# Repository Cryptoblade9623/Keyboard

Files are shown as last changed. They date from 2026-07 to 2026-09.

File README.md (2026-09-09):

# Keyboard
A custom keyboard with a white sakura theme and a rotary encoder.
I'm making this keyboard to have an upgrade from my dying membrane keyboard that also have a lot of the keycaps missing.
I also hope that this will give me some more experience in designing PCBs and 3D models.
Because it is quite a large keyboard that I will be 3D - printing in different parts, I found some metal rods to hold them together and provide some structural support.





Instructions

1.Solder all the diodes on to the PCB

2.Place all the Mill-Max hotswap sockets into their holes

3.Stick heat resistant tape over them in top rows to keep them in place while soldering

4.Solder all the hotswap sockets

5.Solder the pin headers

6.Solder the ESP32 onto the pin headers

7.Solder the Ec11x rotary encoder on to the PCB

8.Flash the ESP32 with the firmware

9.Screw in the PCB-mount stabilizers

10.Solder 4 wires onto the 4 pads of the USBC breakout board

11.Solder 2 small capacitors and 1 big capacitor in parallel on the 5V and GND wires

12.Place heat shrink tubing to cover the solder joints on the wires 

13.Superglue the USBC board into its slot inside the Left-Base part

14.Cut the all the metal rods to 50mm

15.Join the Base pieces together with the metal rods in their slots

16.Join all the Border pieces together again using the metal rods

17.Superglue all the mountain, sakura, grass and tree pieces onto the Scenery Border piece

18.Superglue both halves of the plate together

19.Press the heat set inserts into the Border piece with a soldering iron.

20.Slot the loose wires of the USBC board though the vertical slot hole in the PCB

21.Solder the USBC wires to the D+, D-, GND and RAW of the MCU

22.Stack the parts in the order: base, PCB, plate, border and screw them all together using the M3 bolts

23.Push in the switches

24.Push in all the keycaps onto their assigned switches

25.Snap both pieces of the knob together and push the combined knob onto the rotary encoder stem

And you're done!

| Name | Purpose | Price (USD) | Seller | Link |

| :--- | :--- | :--- | :--- |

| Screws & Standoffs | Spacing, mounting, and securing internal circuit boards | $2.23 | AliExpress |[Link](https://www.aliexpress.com/item/1005008314123679.html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)|

| 100nF Capacitors | Providing smooth current flow to the MCU | $2.27 | AliExpress |[Link](https://www.aliexpress.com/item/1005008314123679.html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)|

| PCB Stabilizers | Stabilizing large mechanical keyboard keys (e.g., Spacebar, Shift) | $10.58 | AliExpress |[Link](https://www.aliexpress.com/item/4001143514438.html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)|

| Keycaps | Providing durable, custom keycaps for mechanical keyboards | $7.74 | AliExpress |[Link](https://www.aliexpress.com/item/4001143514438.html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)|

| Mechanical Switches | Actuating keystrokes quietly and smoothly in hot-swap keyboards | $19.67 | AliExpress |[Link](https://www.aliexpress.com/item/1005012344423067.html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)|

| Rotary Encoder | Providing rotary control and navigation inputs | $2.75 | AliExpress |[Link](https://www.aliexpress.com/item/1005012344423067.html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)|

| Development Board | Processing core logic, Wi-Fi, and Bluetooth functions | $7.10 | AliExpress |[Link](https://www.aliexpress.com/item/1005007319706057.html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)|

| Hot-swap PCB Sockets | Enabling easy and simple mechanical switch replacement on a custom PCB | $14.77 | AliExpress |[Link](https://www.aliexpress.com/item/1005007319706057.html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)|

| USB Type-C Connector | Providing power delivery and data transfer interfaces | $1.25 | AliExpress |[Link](https://www.aliexpress.com/item/1005007319706057.html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)|

| Steel Rod Axles | Acting as structural pins or shafts for moving components | $4.58 | AliExpress |[Link](https://www.aliexpress.com/item/1005007319706057.html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)|

| Heatshrink | Cover soldered wire joints to prevent shorting | $0.85 | AliExpress |[Link](https://www.aliexpress.com/item/1005008538975205.html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)|

| 10uF Capacitors | Providing smooth current flow to the MCU | $1.42 | AliExpress |[Link](https://www.aliexpress.com/item/1005008538975205.html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)|

| Threaded Heat Set Inserts | Providing a thread to screw into | $2.30 | AliExpress |[Link](https://www.aliexpress.com/item/1005008666672949.html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)|

| Copper Braid | Remove excess solder | $3.16 | AliExpress |[Link](https://www.aliexpress.com/item/1005008666672949.html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|)

| Custom PCB | Connecting all the mechanical switches and rotary encoder to the MCU | $28.80 | JLCPCB |-|

| 3D Printed Case | Physical housing or structural frame for the custom keyboard | $3.00 | Printing Legion |-|

| Shipping and Taxes - $16.47

| Grand Total - $128.94|

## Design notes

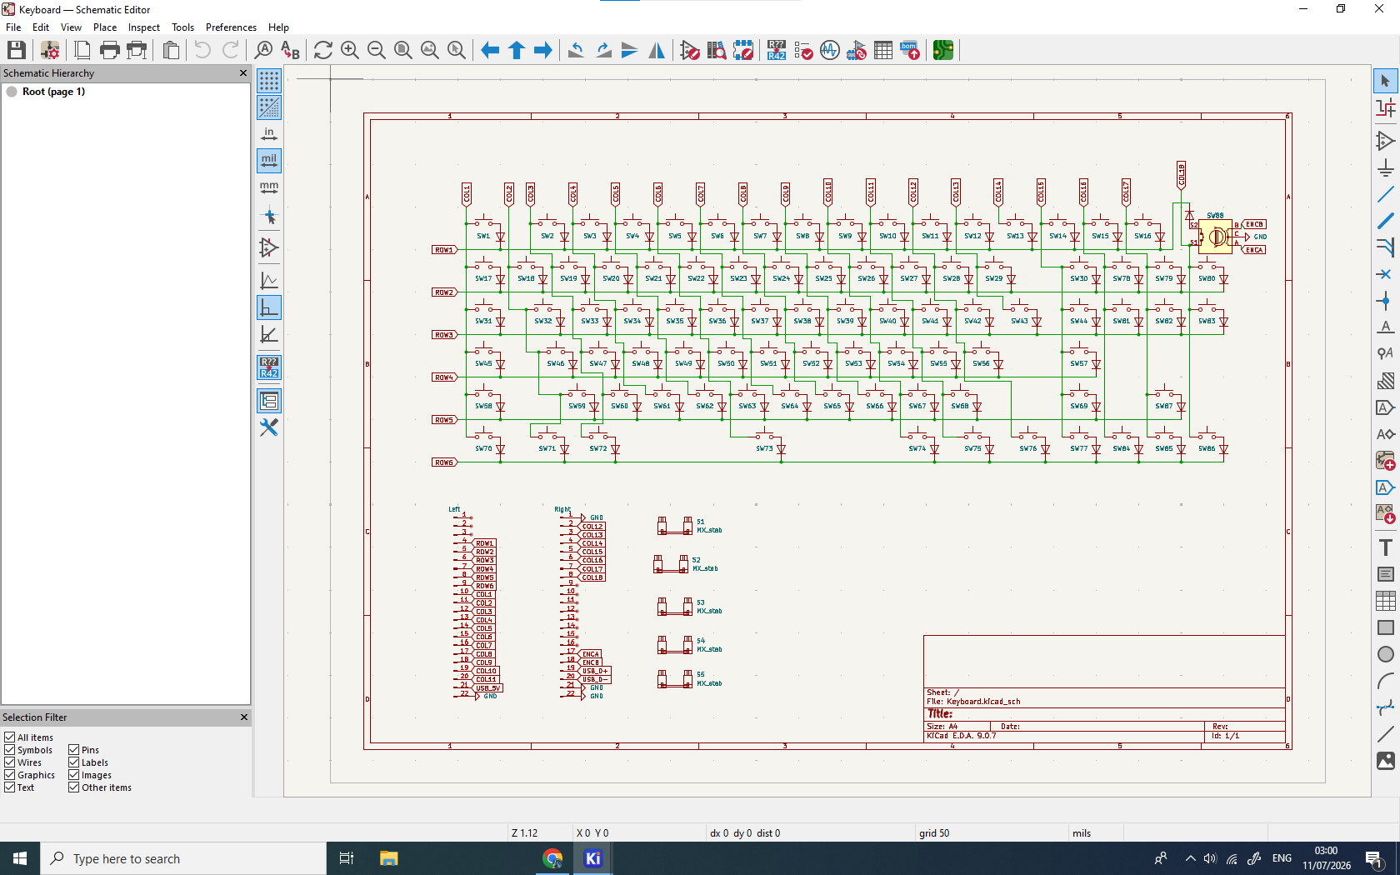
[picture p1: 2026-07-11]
Pictures/Schematic.png

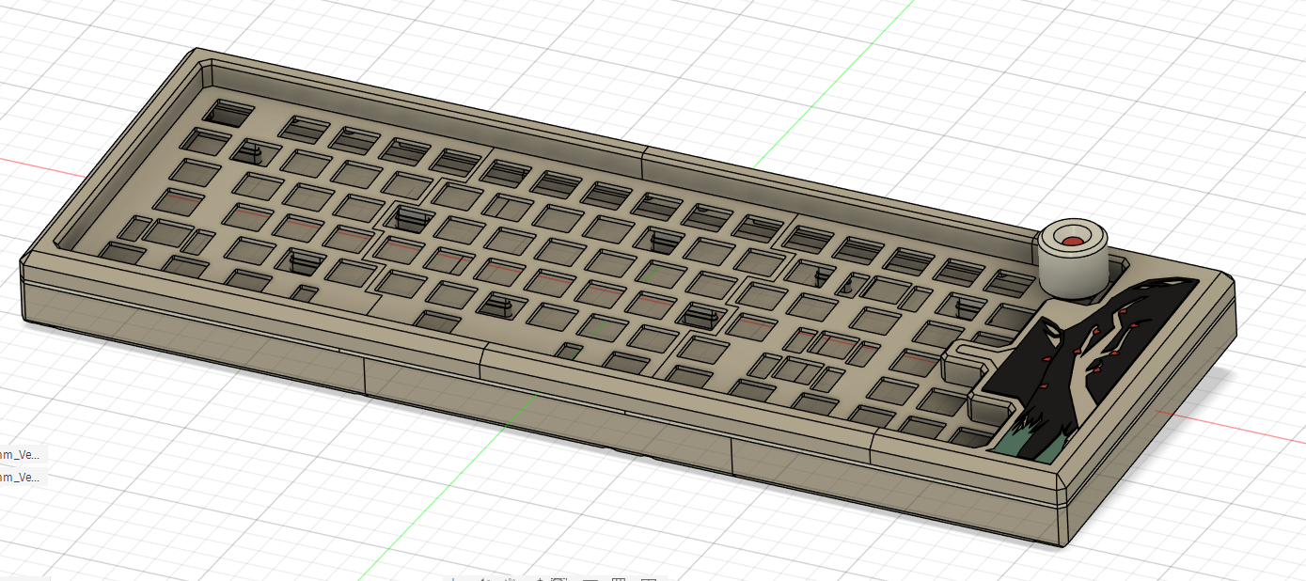
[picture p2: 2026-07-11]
Pictures/Screenshot 2026-06-25 210934.png

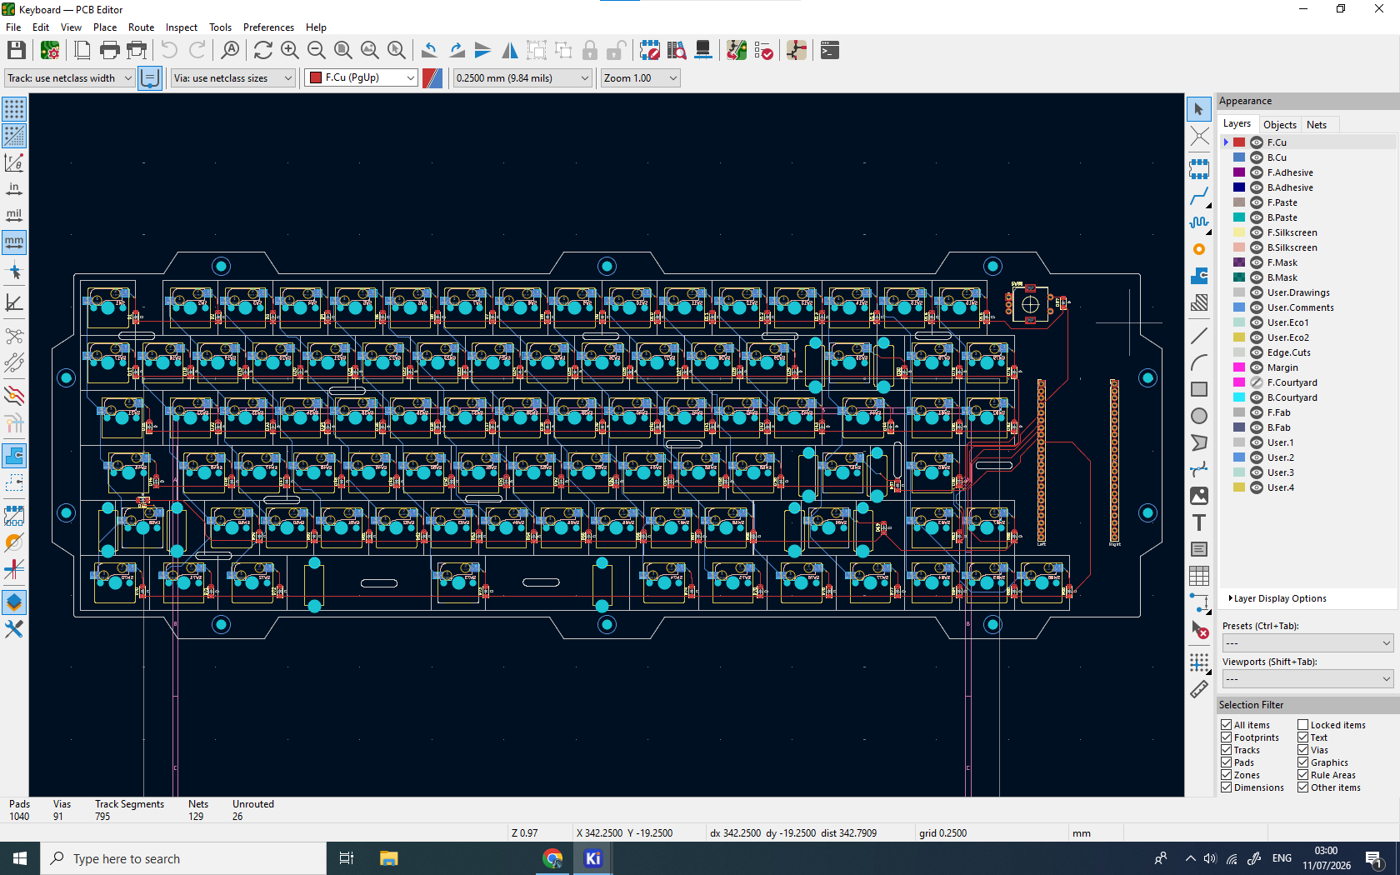
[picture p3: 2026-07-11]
Pictures/PCB.png

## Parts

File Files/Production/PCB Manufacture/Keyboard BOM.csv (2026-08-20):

Name | Purpose | Price | Seller | Link
Screws | Mounting and securing 3D printed parts | $2.23 | AliExpress | https://www.aliexpress.com/item/1005008314123679.html?mp=1
Stabilizers | Preventing keycap rattle for larger keys | $10.58 | AliExpress | https://www.aliexpress.com/item/4001143514438.html?mp=1
Keycaps | Providing a solid surface to type on | $7.74 | AliExpress | https://www.aliexpress.com/item/1005009314900504.html?mp=1
Mechanical Swiches | Registering keystrokes and completing a circuit to alert the MCU | $19.67 | AliExpress | https://www.aliexpress.com/item/1005012344423067.html?mp=1
Rotary Encoder | Providing volume control | $2.75 | AliExpress | https://www.aliexpress.com/item/1005005983134515.html?mp=1
Development Board | Controlling the enitre board and sending signals to the computer | $7.10 | AliExpress | https://www.aliexpress.com/item/1005007319706057.html?mp=1
Hotswap Sockets | Enabling future customizability | $14.77 | AliExpress | https://www.aliexpress.com/item/1005008467527706.html?mp=1
USBC breakout board | Provding power from the computer and data to the computer | $1.25 | AliExpress | https://www.aliexpress.com/item/1005004796961137.html?mp=1
Steel rods | Providing structural support | $4.58 | AliExpress | https://www.aliexpress.com/item/1005009384686024.html?mp=1
Copper Braid | Remove excess solder | $3.16 | AliExpress | https://www.aliexpress.com/item/1005006361511422.html?mp=1
Heatshrink | Cover soldered wire joints | $0.85 | AliExpress | https://www.aliexpress.com/item/1005008538975205.html?mp=1
10uF Capcitor | Smooth power intake to the MCU | $1.42 | AliExpress | https://www.aliexpress.com/item/1005011924154857.html?mp=1
0.1uF Capacitor | Smooth power intake to the MCU | $2.27 | AliExpress | https://www.aliexpress.com/item/1005004982415166.html?scm_id=1007.40050.354490.0&scm-url=1007.40050.354490.0
Threaded Inserts | Providing a thread to screw into | $2.30 | AliExpress | https://www.aliexpress.com/item/1005008666672949.html?curPageLogUid=Rat0uCX0YUx0
PCB | Connecting all the swiches to the MCU | $28.80 | JLCPCB | https://cart.jlcpcb.com/shopcart/cartEdit/?id=c33698ba8980452dbe9859648d54b1e7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
3D Printed Parts | Physical housing | $3.00 | Printing Legion | -
Shipping % Taxes |  | $16.47
Total |  | $128.94

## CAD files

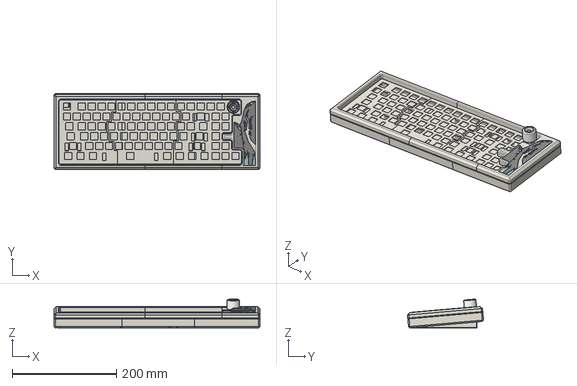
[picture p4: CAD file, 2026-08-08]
Files/Production/3D Files/.step/Keyboard19.step
395.7 x 146.2 x 55.5 mm
D_SOD-123 x 88
旋转编码器

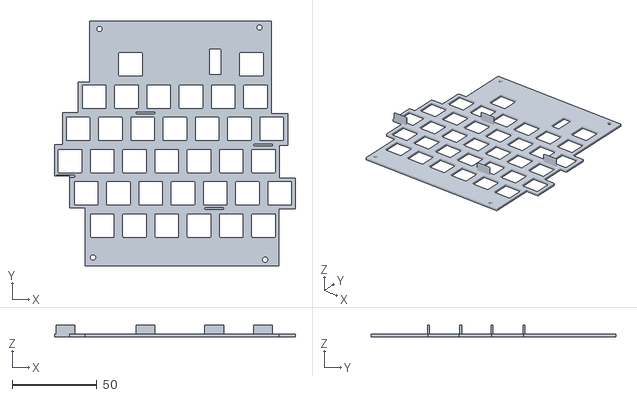
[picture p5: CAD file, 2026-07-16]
Files/Production/3D Files/.stl/Middle Plate.stl.stl
142.4 x 144.8 x 6.96

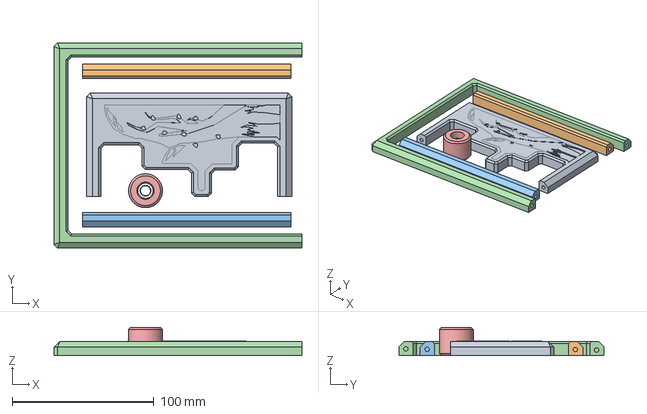
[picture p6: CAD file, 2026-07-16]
Files/Production/3D Files/.step/Borders + Knob Top.step
175.0 x 144.8 x 20.0 mm
D_SOD-123 x 88

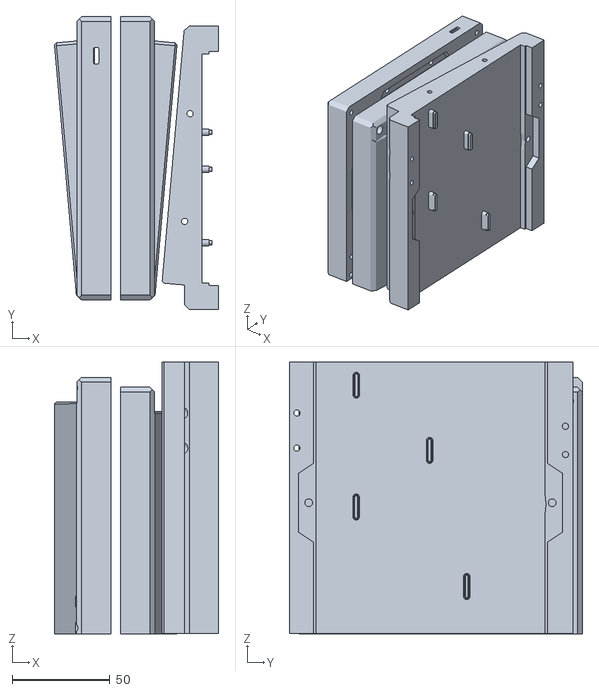
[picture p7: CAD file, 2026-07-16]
Files/Production/3D Files/.stl/Base.stl
83.8 x 149.6 x 138.6

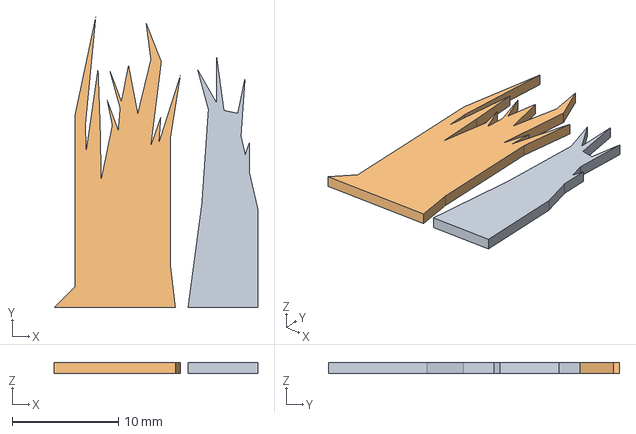
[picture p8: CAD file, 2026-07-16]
Files/Production/3D Files/.step/Grass.step
19.2 x 27.4 x 1.05 mm
D_SOD-123 x 88

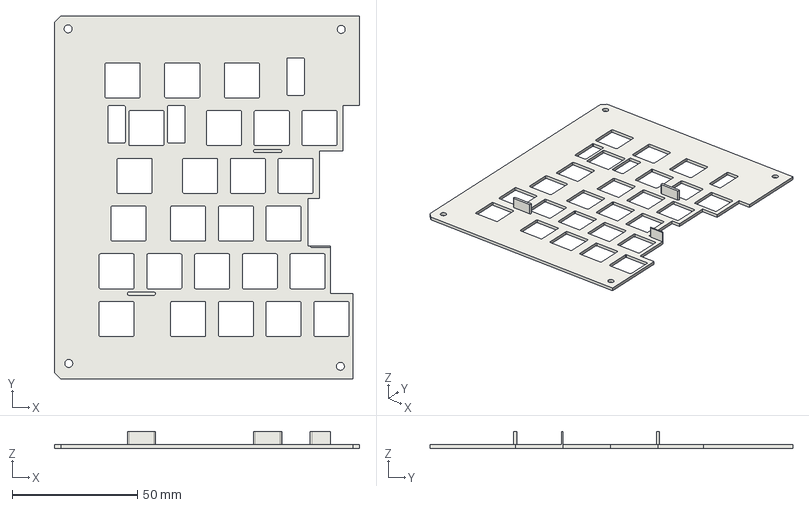
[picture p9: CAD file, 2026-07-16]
Files/Production/3D Files/.step/Left Plate.step
121.7 x 144.8 x 6.96 mm
D_SOD-123 x 88

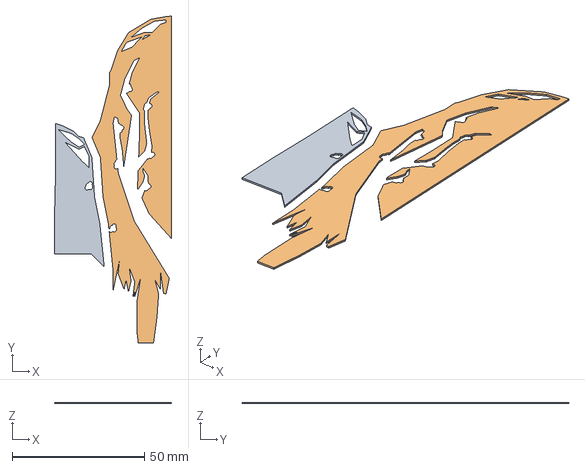
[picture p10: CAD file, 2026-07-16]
Files/Production/3D Files/.step/Mountains.step
44.3 x 123.6 x 0.55 mm
D_SOD-123 x 88

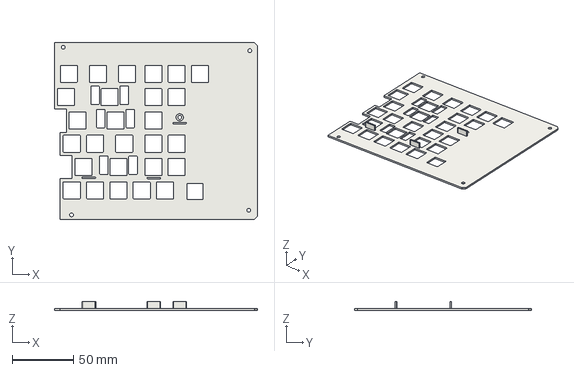
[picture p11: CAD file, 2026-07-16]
Files/Production/3D Files/.step/Right Plate.step
166.0 x 144.8 x 6.96 mm
D_SOD-123 x 88

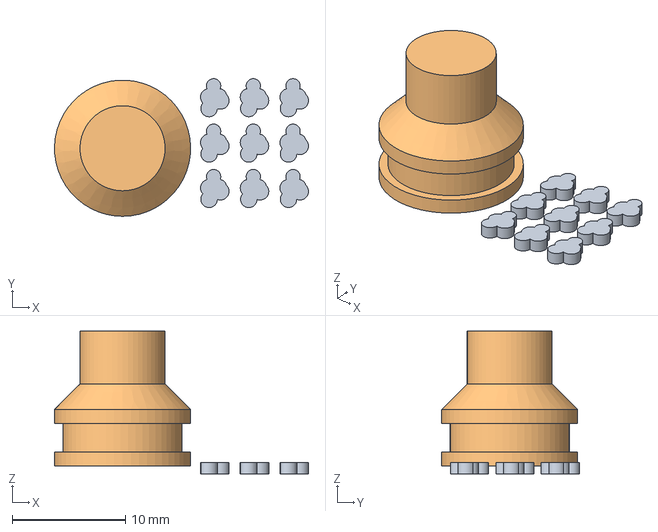
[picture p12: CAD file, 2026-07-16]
Files/Production/3D Files/.step/Sakura + Knob Inside.step
22.4 x 12.1 x 12.6 mm
D_SOD-123 x 88

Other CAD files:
Files/Production/3D Files/.step/Middle Plate.step
Files/Production/3D Files/.stl/Borders + Knob Top.stl
Files/Production/3D Files/.stl/Grass.stl
Files/Production/3D Files/.stl/Keyboard19.stl
Files/Production/3D Files/.stl/Left Plate.stl
Files/Production/3D Files/.stl/Mountains.stl
Files/Production/3D Files/.stl/Right Plate.stl
Files/Production/3D Files/.stl/Sakura + Knob Inside.stl

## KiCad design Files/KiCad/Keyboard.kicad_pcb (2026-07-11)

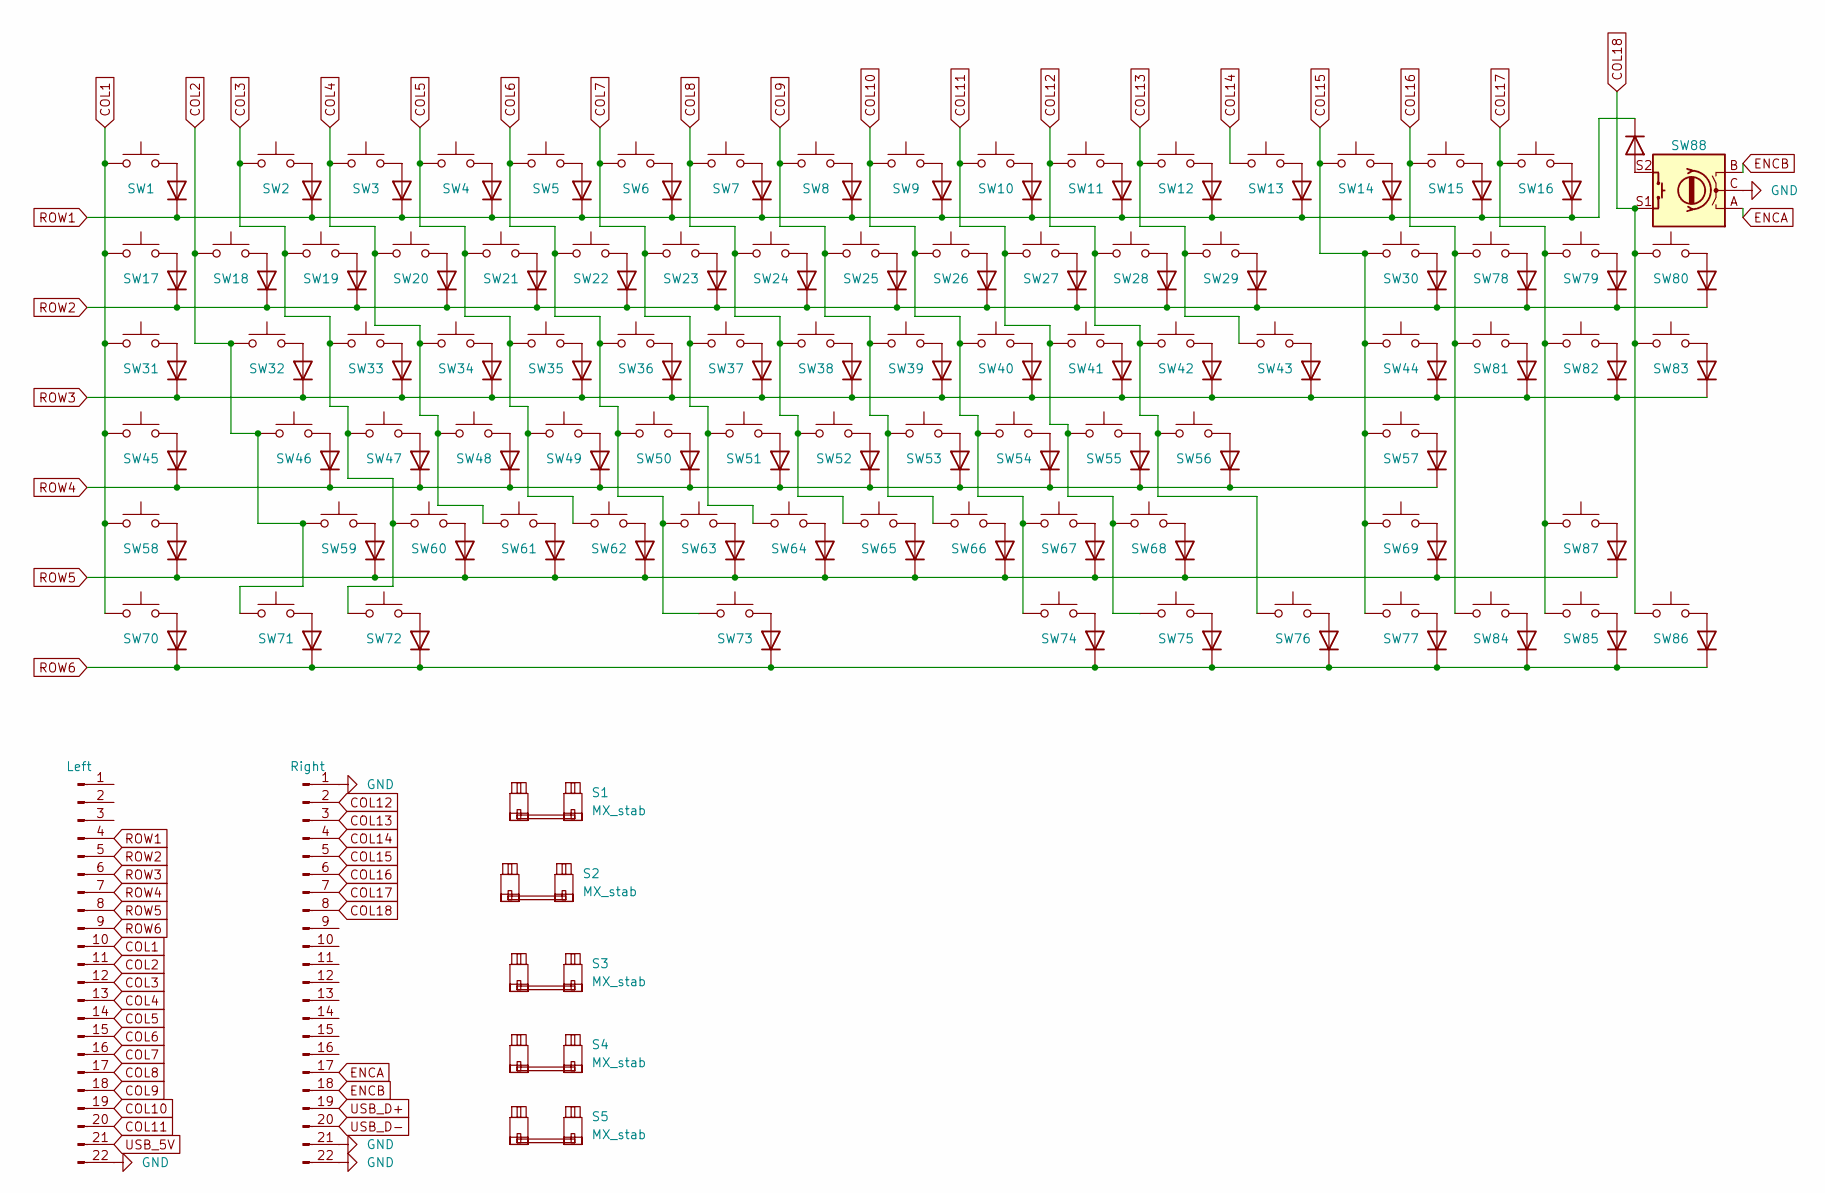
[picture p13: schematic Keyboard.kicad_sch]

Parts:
D1, D2, D3, D4, D5, D6, D7, D8, D9, D10, D11, D12, D13, D14, D15, D16, D17, D18, D19, D20, D21, D22, D23, D24, D25, D26, D27, D28, D29, D30, D31, D32, D33, D34, D35, D36, D37, D38, D39, D40, D41, D42, D43, D44, D45, D46, D47, D48, D49, D50, D51, D52, D53, D54, D55, D56, D57, D58, D59, D60, D61, D62, D63, D64, D65, D66, D67, D68, D69, D70, D71, D72, D73, D74, D75, D76, D77, D78, D79, D80, D81, D82, D83, D84, D85, D86, D87, D88: D; D_SOD-123
J1: Left; PinHeader_1x22_P2.54mm_Vertical
J2: Right; PinHeader_1x22_P2.54mm_Vertical
S1: MX_stab; STAB_MX_2u
S2, S3: MX_stab; STAB_MX_2.25u
S4: MX_stab; STAB_MX_2.75u
S5: MX_stab; STAB_MX_6.25u
SW1, SW2, SW3, SW4, SW5, SW6, SW7, SW8, SW9, SW10, SW11, SW12, SW13, SW14, SW15, SW16, SW17, SW18, SW19, SW20, SW21, SW22, SW23, SW24, SW25, SW26, SW27, SW28, SW29, SW30, SW32, SW33, SW34, SW35, SW36, SW37, SW38, SW39, SW40, SW41, SW42, SW43, SW46, SW47, SW48, SW49, SW50, SW51, SW52, SW53, SW54, SW55, SW56, SW57, SW58, SW59, SW60, SW61, SW62, SW63, SW64, SW65, SW66, SW67, SW68, SW69, SW73, SW78, SW79, SW80, SW81, SW82, SW83, SW84, SW85, SW86, SW87: SW_Push; SW_MX_HS_CPG151101S11_1u
SW31, SW44: SW_Push; SW_MX_HS_CPG151101S11_1.5u
SW45: SW_Push; SW_MX_HS_CPG151101S11_1.75u
SW70, SW71, SW72, SW74, SW75, SW76, SW77: SW_Push; SW_MX_HS_CPG151101S11_1.25u
SW88: RotaryEncoder_Switch; RotaryEncoder_Alps_EC11E-Switch_Vertical_H20mm

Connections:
COL1: J1.10, SW1.1, SW17.1, SW31.1, SW45.1, SW58.1, SW70.1
COL2: J1.11, SW18.1, SW32.1, SW46.1, SW59.1, SW71.1
COL3: J1.12, SW2.1, SW19.1, SW33.1, SW47.1, SW60.1, SW72.1
COL4: J1.13, SW3.1, SW20.1, SW34.1, SW48.1, SW61.1
COL5: J1.14, SW4.1, SW21.1, SW35.1, SW49.1, SW62.1
COL6: J1.15, SW5.1, SW22.1, SW36.1, SW50.1, SW63.1, SW73.1
COL7: J1.16, SW6.1, SW23.1, SW37.1, SW51.1, SW64.1
COL8: J1.17, SW7.1, SW24.1, SW38.1, SW52.1, SW65.1
COL9: J1.18, SW8.1, SW25.1, SW39.1, SW53.1, SW66.1
COL10: J1.19, SW9.1, SW26.1, SW40.1, SW54.1, SW67.1, SW74.1
COL11: J1.20, SW10.1, SW27.1, SW41.1, SW55.1, SW68.1, SW75.1
COL12: J2.2, SW11.1, SW28.1, SW42.1, SW56.1, SW76.1
COL13: J2.3, SW12.1, SW29.1, SW43.1
COL14: J2.4, SW13.1
COL15: J2.5, SW14.1, SW30.1, SW44.1, SW57.1, SW69.1, SW77.1
COL16: J2.6, SW15.1, SW78.1, SW81.1, SW84.1
COL17: J2.7, SW16.1, SW79.1, SW82.1, SW85.1, SW87.1
COL18: J2.8, SW80.1, SW83.1, SW86.1, SW88.S1
ENCA: J2.17, SW88.A
ENCB: J2.18, SW88.B
GND: J1.22, J2.1, J2.21, J2.22, SW88.C
unnamed: D1.2 (A), SW1.2
unnamed: D2.2 (A), SW2.2
unnamed: D3.2 (A), SW3.2
unnamed: D4.2 (A), SW4.2
unnamed: D5.2 (A), SW5.2
unnamed: D6.2 (A), SW6.2
unnamed: D7.2 (A), SW7.2
unnamed: D8.2 (A), SW8.2
unnamed: D9.2 (A), SW9.2
unnamed: D10.2 (A), SW10.2
unnamed: D11.2 (A), SW11.2
unnamed: D12.2 (A), SW12.2
unnamed: D13.2 (A), SW13.2
unnamed: D14.2 (A), SW14.2
unnamed: D15.2 (A), SW15.2
unnamed: D16.2 (A), SW16.2
unnamed: D17.2 (A), SW17.2
unnamed: D18.2 (A), SW18.2
unnamed: D19.2 (A), SW19.2
unnamed: D20.2 (A), SW20.2
unnamed: D21.2 (A), SW21.2
unnamed: D22.2 (A), SW22.2
unnamed: D23.2 (A), SW23.2
unnamed: D24.2 (A), SW24.2
unnamed: D25.2 (A), SW25.2
unnamed: D26.2 (A), SW26.2
unnamed: D27.2 (A), SW27.2
unnamed: D28.2 (A), SW28.2
unnamed: D29.2 (A), SW29.2
unnamed: D30.2 (A), SW30.2
unnamed: D31.2 (A), SW31.2
unnamed: D32.2 (A), SW32.2
unnamed: D33.2 (A), SW33.2
unnamed: D34.2 (A), SW34.2
unnamed: D35.2 (A), SW35.2
unnamed: D36.2 (A), SW36.2
unnamed: D37.2 (A), SW37.2
unnamed: D38.2 (A), SW38.2
unnamed: D39.2 (A), SW39.2
unnamed: D40.2 (A), SW40.2
unnamed: D41.2 (A), SW41.2
unnamed: D42.2 (A), SW42.2
unnamed: D43.2 (A), SW43.2
unnamed: D44.2 (A), SW44.2
unnamed: D45.2 (A), SW45.2
unnamed: D46.2 (A), SW46.2
unnamed: D47.2 (A), SW47.2
unnamed: D48.2 (A), SW48.2
unnamed: D49.2 (A), SW49.2
unnamed: D50.2 (A), SW50.2
unnamed: D51.2 (A), SW51.2
unnamed: D52.2 (A), SW52.2
unnamed: D53.2 (A), SW53.2
unnamed: D54.2 (A), SW54.2
unnamed: D55.2 (A), SW55.2
unnamed: D56.2 (A), SW56.2
unnamed: D57.2 (A), SW57.2
unnamed: D58.2 (A), SW58.2
unnamed: D59.2 (A), SW59.2
unnamed: D60.2 (A), SW60.2
unnamed: D61.2 (A), SW61.2
unnamed: D62.2 (A), SW62.2
unnamed: D63.2 (A), SW63.2
unnamed: D64.2 (A), SW64.2
unnamed: D65.2 (A), SW65.2
unnamed: D66.2 (A), SW66.2
unnamed: D67.2 (A), SW67.2
unnamed: D68.2 (A), SW68.2
unnamed: D69.2 (A), SW69.2
unnamed: D70.2 (A), SW70.2
unnamed: D71.2 (A), SW71.2
unnamed: D72.2 (A), SW72.2
unnamed: D73.2 (A), SW73.2
unnamed: D74.2 (A), SW74.2
unnamed: D75.2 (A), SW75.2
unnamed: D76.2 (A), SW76.2
unnamed: D77.2 (A), SW77.2
unnamed: D78.2 (A), SW78.2
unnamed: D79.2 (A), SW79.2
unnamed: D80.2 (A), SW80.2
unnamed: D81.2 (A), SW81.2
unnamed: D82.2 (A), SW82.2
unnamed: D83.2 (A), SW83.2
unnamed: D84.2 (A), SW84.2
unnamed: D85.2 (A), SW85.2
unnamed: D86.2 (A), SW86.2
unnamed: D87.2 (A), SW88.S2
unnamed: D88.2 (A), SW87.2
ROW1: D1.1 (K), D2.1 (K), D3.1 (K), D4.1 (K), D5.1 (K), D6.1 (K), D7.1 (K), D8.1 (K), D9.1 (K), D10.1 (K), D11.1 (K), D12.1 (K), D13.1 (K), D14.1 (K), D15.1 (K), D16.1 (K), D87.1 (K), J1.4
ROW2: D17.1 (K), D18.1 (K), D19.1 (K), D20.1 (K), D21.1 (K), D22.1 (K), D23.1 (K), D24.1 (K), D25.1 (K), D26.1 (K), D27.1 (K), D28.1 (K), D29.1 (K), D30.1 (K), D78.1 (K), D79.1 (K), D80.1 (K), J1.5
ROW3: D31.1 (K), D32.1 (K), D33.1 (K), D34.1 (K), D35.1 (K), D36.1 (K), D37.1 (K), D38.1 (K), D39.1 (K), D40.1 (K), D41.1 (K), D42.1 (K), D43.1 (K), D44.1 (K), D81.1 (K), D82.1 (K), D83.1 (K), J1.6
ROW4: D45.1 (K), D46.1 (K), D47.1 (K), D48.1 (K), D49.1 (K), D50.1 (K), D51.1 (K), D52.1 (K), D53.1 (K), D54.1 (K), D55.1 (K), D56.1 (K), D57.1 (K), J1.7
ROW5: D58.1 (K), D59.1 (K), D60.1 (K), D61.1 (K), D62.1 (K), D63.1 (K), D64.1 (K), D65.1 (K), D66.1 (K), D67.1 (K), D68.1 (K), D69.1 (K), D88.1 (K), J1.8
ROW6: D70.1 (K), D71.1 (K), D72.1 (K), D73.1 (K), D74.1 (K), D75.1 (K), D76.1 (K), D77.1 (K), D84.1 (K), D85.1 (K), D86.1 (K), J1.9
USB_5V: J1.21
USB_D+: J2.19
USB_D-: J2.20

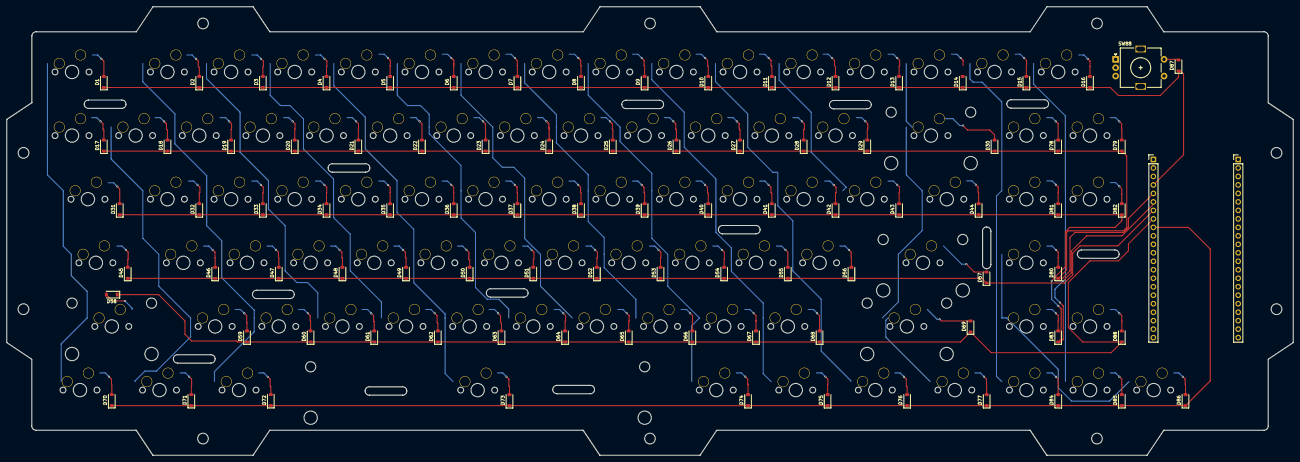
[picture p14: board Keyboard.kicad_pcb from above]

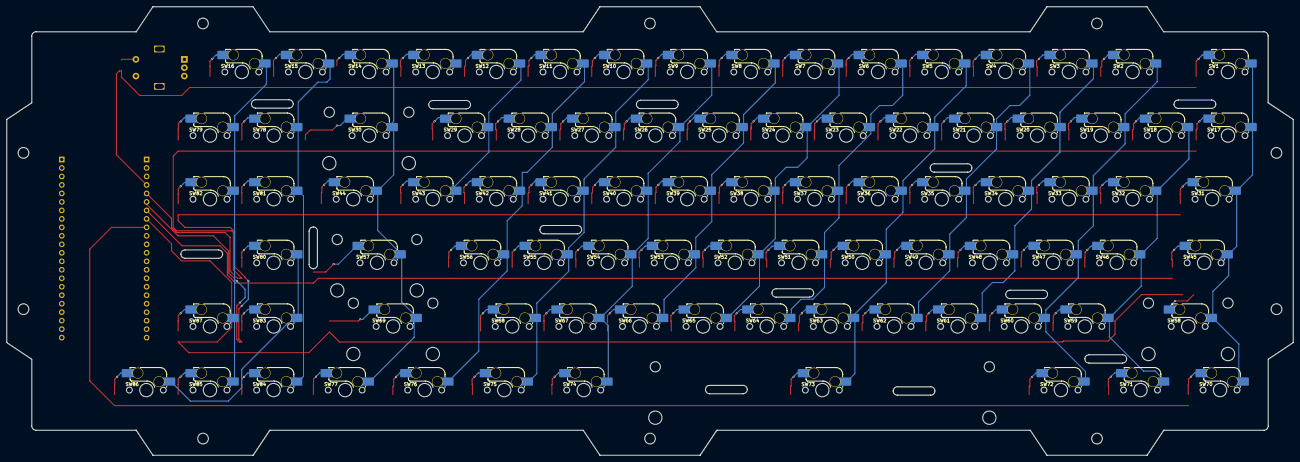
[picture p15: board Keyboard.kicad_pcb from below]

Board: 2 copper layers, 385.2 x 134.3 mm, 183 parts (87 on the bottom side), 115 nets.

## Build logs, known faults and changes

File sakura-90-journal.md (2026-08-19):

# Sakura 90

A mechanical keyboard with 88 keys, a rotary encoder and a sakura theme.

# 2026-08-19: More Rejection Problems

**Total time spent: 45 mins**

Tried to fix the problems in the design, also made some more adjustments to the 3D files and the PCB.


# 2026-08-19: Rejection Problems

**Total time spent: 1 hour**

I've tried to fix the problems with the design and the repo because it rejected. I organized the files, added more pictures and fixed the BOM formatting issues.


# 2026-08-19: Github Repo

**Total time spent: 2.5 hours**

Today I finished the repository in Github. The readme has a small intro to the project along with a picture and a BOM in table form. There are also all the KiCad files used, along with the BOM in csv format, gerber file and 3D files in both step and stl formats.


# 2026-08-19: Scenery

**Total time spent: 1.5 hours**

I thought a plain white build would look a bit boring so I decided to add a sakura landscape. I spent literally ages trying find image to use as a DXF but they were all too big and the wrong format. I tried converting them but they still ended up too big. In the end I decided to make my own so I started adding the lines on the surface in a sketch to make 2 mountains, a cherry blossom branch and 2 patches of grass coming in from either side. I then offset them by 0.1mm and extruded them downwards and then extruded the un-offset shape in the sketch to make a flat piece of colored plastic that I could just superglue in.


# 2026-08-19: Border Design

**Total time spent: 45 mins**

Since exposing the switches would look a bit crappy I decided to add a border that covers them up. I calculated the edges and width of the borders. I tried to loft it up using the loft tool but that did not work so I extruded the outline and then chamfered the edges. I also added the holes for the threaded inserts.


# 2026-08-19: Plate Design

**Total time spent: 15 mins**

The plate did not take as long as the case because all I had to do was import the DXF from AI03 Plate Generator and extrude it to 1.6mm. Then I extruded the borders to match the base and then chamfered the corners. I also added a square hole for the rotary encoder and more M3 screwholes.


# 2026-08-19: Base Design

**Total time spent: 4.5 hours**

In this session I designed the bottom case or base for the keyboard. I has a 5 degree typing angle and the PCB is mounted using tabs and screws. I started by importing the PCB .step file in to Fusion 360 and then offsetting the PCB outline. I then offset that and made the walls. I then created a direct lip all around the inside of the case like a ledge to help hold the PCB. I also helped to hold the PCB using projections that slot into the holes on the bottom of the PCB. I then added slots for the USBC daughterboard. Then came the screw holes and the holes for the metal rods that help hold the 3 parts of the case. I had to do it like that because the person who 3D prints my parts only has a 180mm cubed print bed.



# 2026-08-19: Plate as a DXF

**Total time spent: 30 mins**

I spent sometime creating the layout in a the keyboard layout editor and exported the dxf in the ai03 plate generator. This was because it wouldn't let me export the plate file as a step file in KiCad because of tolerance issues that couldn't seem to be solved.




# 2026-08-19: Plate

**Total time spent: 3 hours**

I created another PCB planning it to be the plate coloured white and to be made of FR-4. I added in the footprints directly from the PCB editor, while making the position of the switch cutouts match the position of the switches match the actual PCB. Then I realised that making the plate as a PCB would be too expense and decided to export the plate as a .step straight from KiCad to design the case.


# 2026-08-19: PCB

**Total time spent: 4 hours**

Managed to finish the entre PCB in one sitting. I started by arranging all the key switches using the position relative to item tool, while making stupidly extensive calculations on paper from the misshapen keys. Once I had placed all the keys and rotary encoder, I wired the entire PCB. After that, I just happened to realize the there would be no space for the chip and if I place it anywhere else it would look really awkward and out of place so I had to rearrange the keys and delete some of the wiring, place the chip, and then wire the section over again. Then I placed the mounting holes and the edge cuts while adding slot cutouts to support it against the plate while placing the key switches.


# 2026-08-19: Schematics

**Total time spent: 3 hours**

I did some research into the ESP32 S3C1 N16R8 chip and its data pins. I'm using an ANSI 80%. I wired all the parts and roughly arranged them in the layout I want for the PCB. Then I assigned all the footprints one by one according the layout and order of parts.



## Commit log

2026-08-10 Update README with details on keyboard construction
    Added information about structural support for 3D-printed parts.
2026-08-21 Update README with assembly instructions
    Added detailed assembly instructions for the PCB project.
2026-08-21 Update README with assembly instructions
    Added detailed assembly instructions for the PCB and components.
2026-08-21 Update README with assembly instructions and images
    Added images and detailed instructions for keyboard assembly.
